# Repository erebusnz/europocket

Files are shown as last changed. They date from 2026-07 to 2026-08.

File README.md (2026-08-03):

# europocket

A Eurorack module that interfaces a **Teenage Engineering Pocket Operator** with a
**Eurorack** modular system. The two domains differ in both clock rate and signal
levels, so the board provides two converters in one:

- **Clock converter** — takes a Eurorack clock/trigger on the input jack and produces
  a Pocket Operator compatible sync signal (÷2, 4 PPQN → 2 PPQN, 0–3.3 V).
- **Level converter** — takes the Pocket Operator's **left and right audio** and
  boosts it from line level to modular level on the two output jacks.

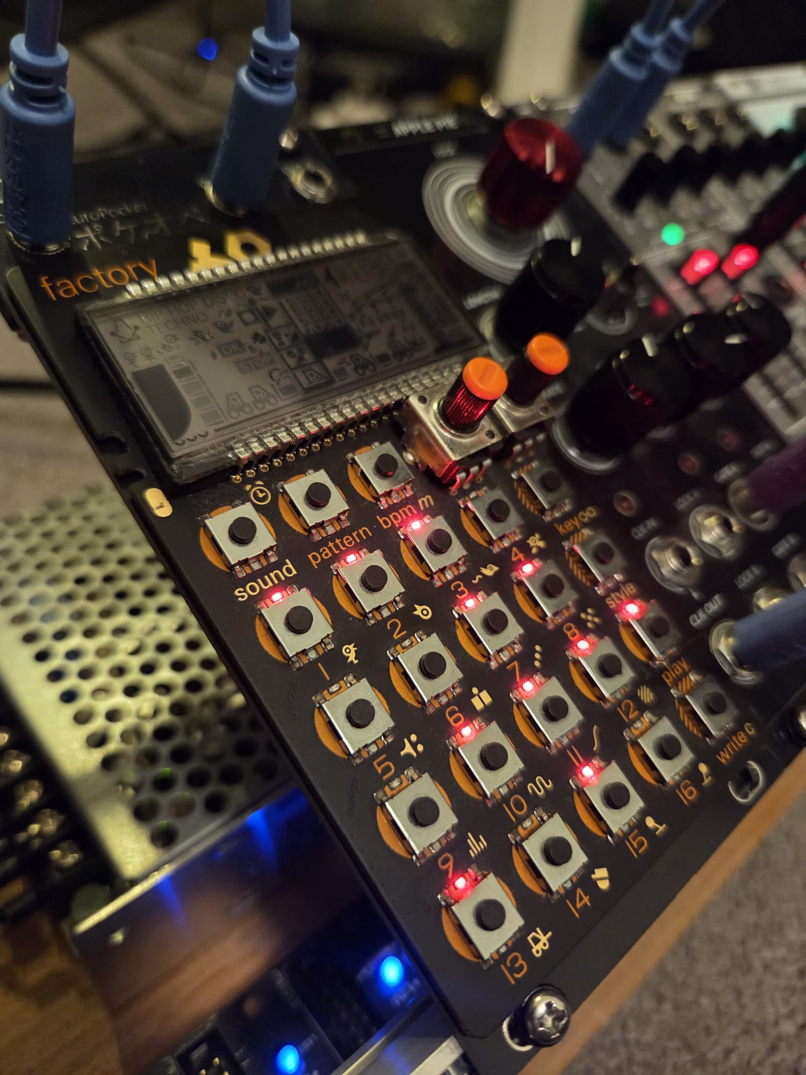
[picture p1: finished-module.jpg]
The finished module installed in a Eurorack case, patched to a PO-32


*The finished module in the rack, clocking and taking audio from a PO-32.*

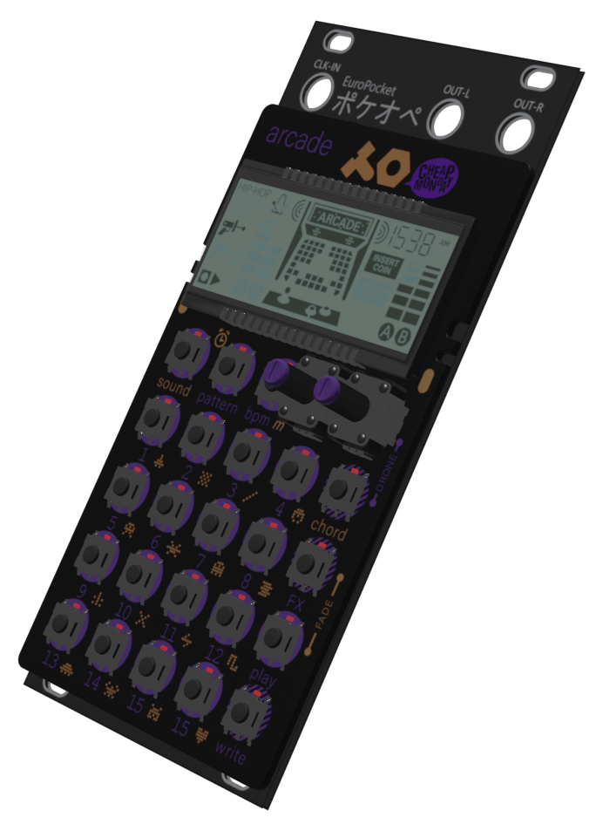
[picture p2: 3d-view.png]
3D view


## Jacks

| Jack | Direction | Signal |
|---|---|---|
| Clock in | Eurorack → board | Eurorack clock/trigger (up to ~10–12 V tolerated) |
| Audio out L | board → Eurorack | Pocket Operator left channel, boosted to ~10 Vpp modular level |
| Audio out R | board → Eurorack | Pocket Operator right channel, boosted to ~10 Vpp modular level |

The Pocket Operator connects via its sync/audio jacks: the converted sync clock goes
to the PO, and the PO's audio comes back into the board's two buffer channels.

## Assembly

> ⚠️ **Use a hot-air rework station.** Attaching europocket requires desoldering the
> jacks from the back of the Pocket Operator. Hot air lifts them cleanly; an iron risks
> pulling the pads off the PO, which is not recoverable.

1. **Desolder the PO's jacks** from the back of the Pocket Operator.
2. **Bond the boards.** Position the europocket PCB on top of the Pocket Operator and
   join the two with **three small sections of 3M 4910F VHB Clear tape**.
3. **Connect the module to the PO.** Solder `PO-R`, `PO-L` and `PO-CLK` to the pads that
   appear in the same box on the Pocket Operator.
4. **Refit the jacks** to the module's own pads — `GND, R, GND, L` for audio and
   `GND, CLK` for the clock.
5. **Wire up Reset.** Solder `Reset` to the **bottom left pin of the Play button** on the
   front of the Pocket Operator, so the divider clears in step with the PO's transport.
6. **Power the PO from the module:**
   - `B−` → **top right** battery terminal
   - `B+` → **bottom left** battery terminal

The module supplies the Pocket Operator from its own +3.3 V regulator in place of the
AAA cells, so the PO runs whenever the rack is powered.

## Pocket Operator setup

Two settings on the PO must be correct or the module will appear dead. Both are
button chords on the master unit.

### Sync mode — set to SY2

> Hold **`key`** and press **`bpm`**. Press repeatedly to cycle through the modes.

**SY2** means *sync in, stereo audio out* — the mode this module expects. It takes the
board's converted clock on its sync input and returns both audio channels.

Pocket Operators share their 3.5 mm jacks between audio and sync, so the other SY modes
repurpose one or both output channels to carry the sync click instead of music. In those
modes the level converter's inputs see **silence**, and the module produces no output
even though every part of it is working correctly.

### Volume — set to full

> Hold **`bpm`** and press **key 16**.

The level converter's gain of ×4.41 is fixed, and it assumes the PO is running at full
output. The ~9.7 Vpp modular-level figure comes from the PO's measured **2.2 Vpp at
loudest volume** — at anything less, the module's output scales down proportionally and
won't reach Eurorack level.

## How it works

**Clock path:** Eurorack trigger → transistor input stage (level shift + protection,
Q1) → RC glitch filter → Schmitt trigger (74AHC1G14) → D flip-flop wired as a toggle
(74HC74, ÷2) → 1 kΩ series output → PO sync. The **Reset** input connects to the
module's Play button and asynchronously clears the divider for deterministic restarts.
Most Eurorack clocks run 4 PPQN; Pocket Operators expect 2 PPQN, hence the
divide-by-two.

**Audio path:** each channel is an inverting TL072 stage running from ±12 V,
gain ≈ ×4.41 (220 kΩ / 49.9 kΩ), taking the PO's measured ~2.2 Vpp output to
~9.7 Vpp. An 18 pF feedback cap rolls off above ~40 kHz — high enough to keep the
PO's square-wave edges crisp.

**Power:** ±12 V from the Eurorack bus (2×05 IDC header, Schottky reverse-polarity
protection). An LM1117 regulates +3.3 V locally for the logic; the TL072 runs
directly from ±12 V.

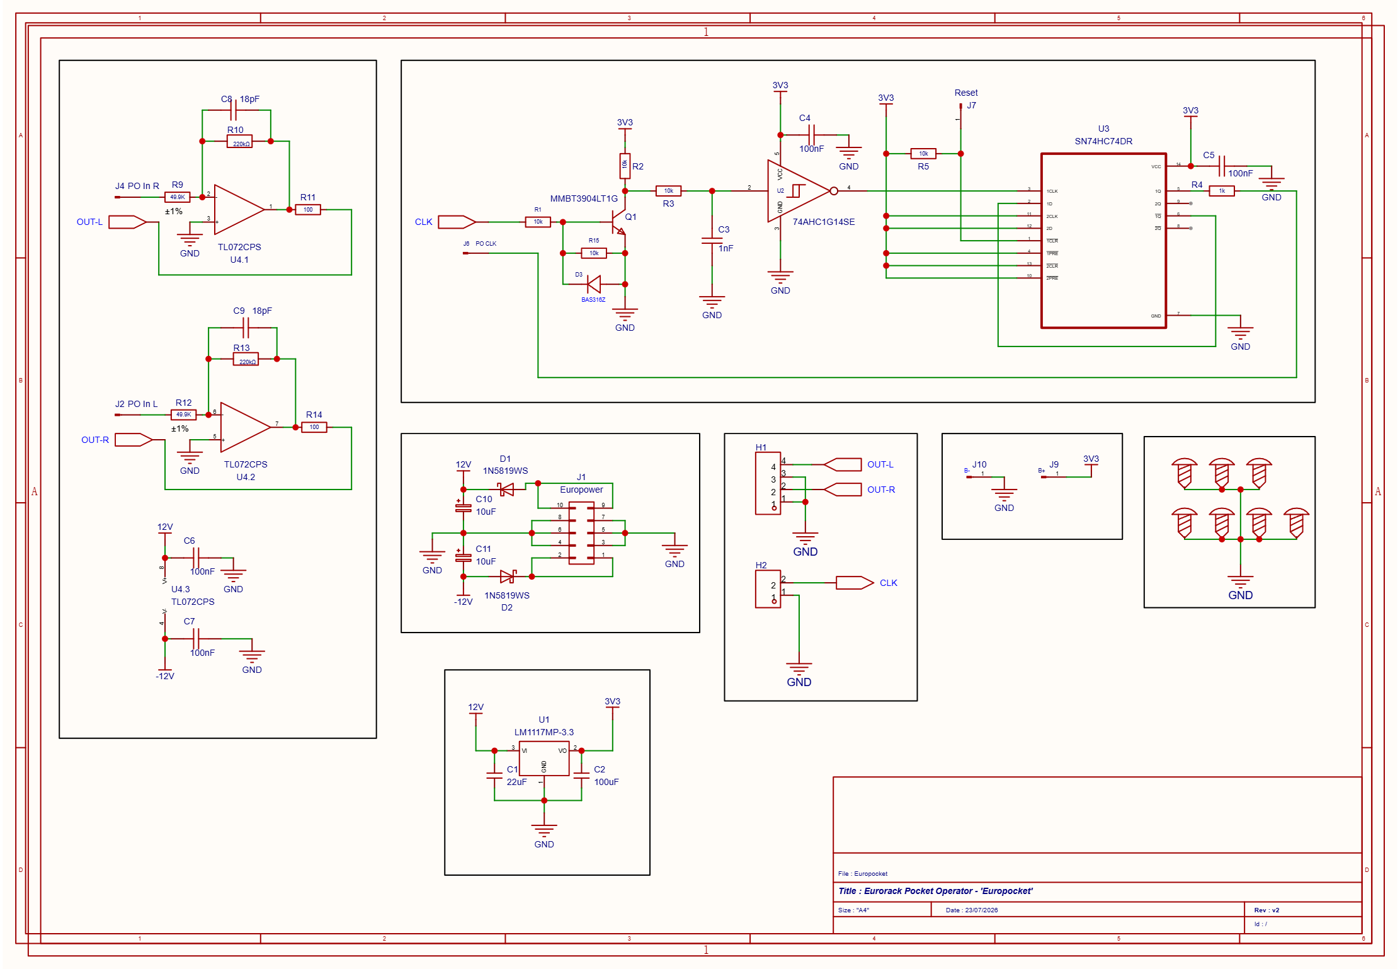
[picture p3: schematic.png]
Schematic


## Bill of materials

**Semiconductors**

| Qty | Reference | Part | Package | Purpose |
|-----|---|---|---|---|
| 1 | U1 | LM1117MP-3.3 | SOT-223 | +12 V → +3.3 V LDO |
| 1 | U2 | 74AHC1G14SE-7 | SOT-353 (SC-70-5) | Schmitt inverter |
| 1 | U3 | SN74HC74DR | SOIC-14 | Dual D flip-flop (÷2) |
| 1 | U4 | TL072CPS | SOIC-8W | Dual op-amp (level converter) |
| 1 | Q1 | MMBT3904LT1G (onsemi) | SOT-23 | NPN input transistor |
| 2 | D1, D2 | 1N5819WS | SOD-123F | Schottky, reverse-polarity protection |
| 1 | D3 | BAS316Z | SOD-323 | Q1 base clamp, negative inputs |

**Resistors** — all 0805

| Qty | Reference | Value | Purpose |
|-----|---|---|---|
| 5 | R1, R2, R3, R5, R15 | 10 kΩ | Base series, collector pull-up, RC filter, /CLR1 pull-up, base pulldown |
| 1 | R4 | 1 kΩ | Sync output series resistor |
| 2 | R9, R12 | 49.9 kΩ | Buffer input resistors |
| 2 | R10, R13 | 220 kΩ | Buffer feedback resistors (×4.41) |
| 2 | R11, R14 | 100 Ω | Buffer output series resistors |

**Capacitors**

| Qty | Reference | Value | Package | Purpose |
|-----|---|---|---|---|
| 4 | C4, C5, C6, C7 | 100 nF | 0805 | Rail decoupling (+3.3 V ×2, +12 V, −12 V) |
| 2 | C8, C9 | 18 pF | 0805 | Buffer feedback caps (~40 kHz pole) |
| 1 | C3 | 1 nF | 0805 | RC filter |
| 1 | C1 | 22 µF | CP_Elec_5×5.3 | +12 V bulk |
| 2 | C10, C11 | 10 µF | CP_Elec_5×5.3 | ±12 V decoupling |
| 1 | C2 | 100 µF | CP_Elec_6.3×5.9 | +3.3 V bulk |

**Connectors and test points**

| Qty | Reference | Part | Purpose |
|-----|---|---|---|
| 1 | J1 | IDC header 2×05 | Eurorack ±12 V / GND bus ("Europower") |
| 1 | H1 | 4-pad row | Audio out L/R + GND |
| 1 | H2 | 2-pin header 2.54 mm | Clock in + GND |
| 6 | J2, J4, J6, J7, J9, J10 | Test pad 4.0×2.0 mm | PO In L/R, PO CLK, Reset, B+, GND |

**Assembly consumables**

| Qty | Item | Purpose |
|-----|---|---|
| 3 | 3M 4910F VHB Clear tape, small sections | Bonding the PCB to the Pocket Operator |

## Repository contents

| File | Description |
|---|---|
| [finished-module.jpg](finished-module.jpg) | Photo of the assembled module in a rack |
| [schematic.pdf](schematic.pdf) / [schematic.png](schematic.png) | Schematic |
| [pcb-top.png](pcb-top.png) / [pcb-bottom.png](pcb-bottom.png) | PCB renders |
| `europocket.eprj2` | EasyEDA Pro project file |
| `gerber/` | Fabrication outputs |
| `datasheets/` | Component datasheets |

## PCB

| Front | Back |
|---|---|
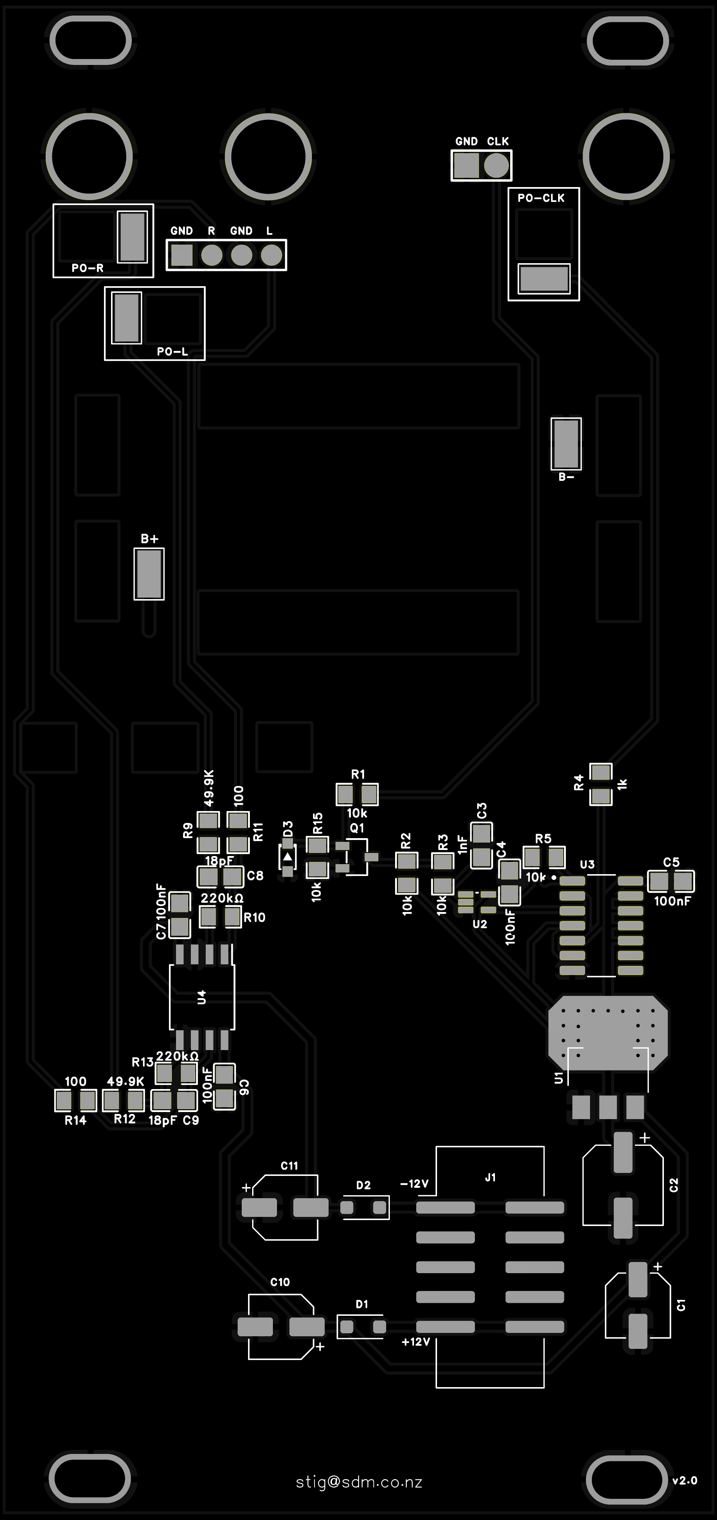
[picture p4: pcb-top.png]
PCB top
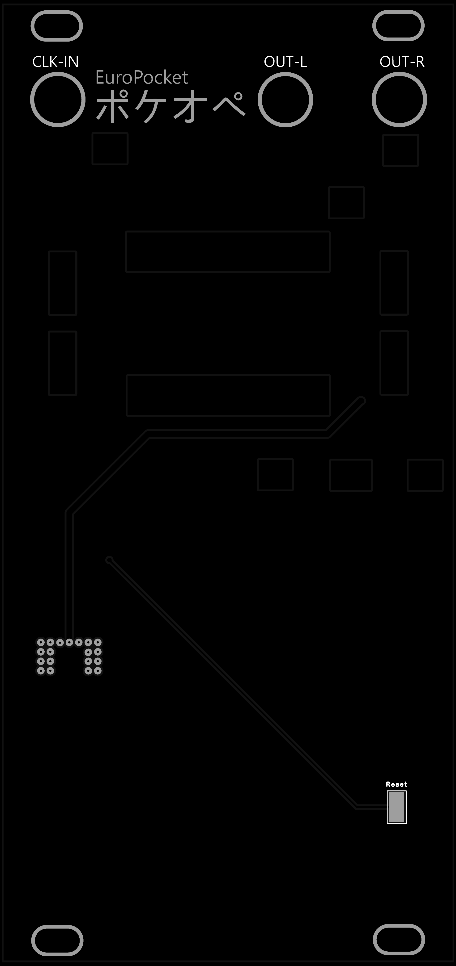
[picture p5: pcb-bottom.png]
PCB bottom
|  |  |

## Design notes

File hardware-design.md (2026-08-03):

# europocket — Hardware Design

Interface between the **Eurorack** and **Pocket Operator (PO)** domains. The two signal
domains differ in both timing (clock rate) and electrical levels, so the design breaks
into three functional blocks: **Power**, **Clock converter**, and **Level converter**.

> Reference designators, values and nets in this document are reconciled against
> `Netlist_europocket_2026-08-03.tel`.
>
> **Designators changed in this revision.** The Europower header moved `J3` → **`J1`**,
> reset moved `J5` → **`J7`**, the buffer and trigger test points were replaced by
> labelled PO test points (`J2`, `J4`, `J6`), and the audio outputs and clock input are
> now headers **`H1`** and **`H2`**. Older notes and captures using the previous
> numbering will not match.

---

## Power

Powered from the **Eurorack bus** via header **J1** ("Europower", 2×05 IDC). The board
takes **±12 V** from the bus and locally regulates **+3.3 V** for the CMOS logic. The
TL072 in the Level converter runs directly from **±12 V**.

**Rails**

| Rail | Source | Consumers |
|---|---|---|
| +12 V | J1 pins 9–10, via D1 | LM1117 input (U1.3), TL072 V+ (U4.8) |
| −12 V | J1 pins 1–2, via D2 | TL072 V− (U4.4) |
| +3.3 V  | LM1117 (U1) output | U2, U3, R2/R5 pull-ups, J9 test point |
| GND | J1 pins 3–8 | all blocks, plus all seven mounting holes |

> **−12 V has exactly one consumer: the op-amp.** Nothing else on the board depends on
> it, so a dead −12 V rail leaves the clock converter working normally while the audio
> path is silent. Check it directly at U4.4 when diagnosing a dead audio path.

**Components**

- `U1` — LM1117MP-3.3 (SOT-223) LDO: **+12 V → +3.3 V** (Vin = U1.3, Vout = U1.2, GND = U1.1).
- `D1`, `D2` — 1N5819WS Schottky, reverse-polarity / mis-insertion protection on the +12 V and −12 V rails.
- Bulk: `C1` 22 µF (+12 V), `C2` 100 µF (+3.3 V), `C10` 10 µF (+12 V), `C11` 10 µF (−12 V).
- Decoupling (100 nF, one per rail/IC, adjacent to the pin): `C4`/`C5` on +3.3 V (U2/U3), `C6` on +12 V, `C7` on −12 V.

Measured on hardware (2026-08-03): **+11.2 V** at U4.8 and **−12.1 V** at U4.4 — the
asymmetry is bus tolerance plus the Schottky drop, and it means the positive half of the
audio waveform clips roughly a volt before the negative half.

---

## Clock converter

### Eurorack Trigger → Pocket Operator Sync Converter

**Purpose.** Convert a Eurorack clock/trigger into a Pocket Operator compatible sync
signal. The design assumes a **4 PPQN** Eurorack clock and produces a **2 PPQN** Pocket
Operator sync clock by dividing the clock by two.

**Requirements**

- Accept Eurorack triggers up to approximately **10–12 V**.
- Protect the logic from overvoltage and from negative excursions.
- Reject narrow glitches.
- Produce clean **3.3 V CMOS** logic.
- Divide clock by two.
- Provide deterministic reset.

#### Functional block diagram

```
Eurorack Trigger (H2.2)
        │
        ▼
Input Protection / Level Shift   (Q1, R1, R15, D3)
        │
        ▼
RC Noise Filter                  (R3 / C3)
        │
        ▼
Schmitt Trigger Inverter         (U2, 74AHC1G14)
        │
        ▼
Toggle Flip-Flop (÷2)            (U3, 74HC74)
        │
        ▼
Pocket Operator Sync Output      (R4 → J6)
```

#### Stage 1 — Input conditioning

**Connector H2 (clock in):** H2.2 = Eurorack clock, H2.1 = GND.

**Components**

- `Q1` — MMBT3904 (SOT-23) NPN
- `R1` — 10 kΩ (base series)
- `R2` — 10 kΩ collector pull-up to 3.3 V
- `R15` — 10 kΩ base–emitter pulldown
- `D3` — SOD-323 small-signal diode, base clamp

**Wiring**

```
Clock input (H2.2) → R1 → Q1 base ─┬─ R15 → GND
                                    └─ D3 cathode (anode → GND)
Q1 emitter    → GND
Q1 collector  → R2 pull-up to 3.3 V   (collector = logic signal)
```

**Behaviour**

| Input | Collector |
|---|---|
| Low | High |
| High  | Low |

The transistor **level shifts**, **protects** the logic, and **inverts**.

**Why R15 and D3 are present.** Without the `R15` pulldown the stage switches at a single
V_BE (~0.65 V). A Eurorack clock source measured on hardware idles **low at ~0.68 V**,
above that threshold — so Q1 never turns off and the collector sticks low. R15 divides the
base voltage and lifts the effective threshold to ~1.3 V:

| Input | Base voltage (with R15) | Q1 |
|---|---|----|
| Low 0.68 V  | ÷2 → 0.34 V | off ✓ |
| High 4.7 V  | Thevenin 2.34 V / 5 kΩ → I_B ≈ 0.33 mA | saturated ✓ |

`D3` clamps negative inputs at −0.6 V. Bipolar Eurorack signals (±5 V/±8 V LFOs, or audio
used as a clock) would otherwise reverse-bias Q1's base–emitter junction; V_EBO(max) is
only 6 V, and repeated B–E avalanche permanently degrades hFE. R1 limits the clamp
current for inputs down to at least −12 V.

#### Stage 2 — Noise filter

**Components:** `R3` = 10 kΩ, `C3` = 1 nF → **time constant ≈ 10 µs**.

```
Q1 collector
     │
     R3
     │
     +------> Schmitt Trigger input (U2.2)
     │
     C3
     │
    GND
```

**Purpose:** remove spikes, slightly slow edges before the Schmitt trigger.

#### Stage 3 — Schmitt trigger

**Device:** `U2` — 74AHC1G14SE-7 (single inverting Schmitt trigger, **SOT-353/SC-70-5** —
the `SE` suffix; 0.65 mm pitch, smaller than SOT-23-5).

- Power: VCC = 3.3 V (U2.5), GND (U2.3), 100 nF decoupling.
- Input: U2.2, from the RC network.
- Output: U2.4, clean digital clock — restores fast logic edges.

#### Stage 4 — Clock divider

**Device:** `U3` — SN74HC74DR (dual D flip-flop, SOIC-14). **First flip-flop only.**

- Power: VCC = 3.3 V (U3.14), GND (U3.7), 100 nF decoupling.
- Clock: `1CLK` (U3.3) ← Schmitt output (U2.4).
- Toggle configuration: `1D` (U3.2) ← `1Q̄` (U3.6) — converts the D flip-flop into a T flip-flop.

**Result:** every rising edge, `1Q` toggles → **output frequency = input frequency / 2**.

**Reset**

External reset via test point **J7 ("Reset")**, asynchronously clearing the first
flip-flop. On the assembled module this connects to the PO's Play button, so the divider
restarts deterministically.

- `/CLR1` (U3.1) — J7 with 10 kΩ pull-up `R5` to 3.3 V; drive low to reset.
- `/PRE1` (U3.4) — tied directly to 3.3 V (inactive).

**Unused second flip-flop.** All four inputs are tied to 3.3 V — `/PRE2` (U3.10),
`2CLK` (U3.11), `2D` (U3.12), `/2CLR` (U3.13). Outputs `2Q` (U3.9) and `2Q̄` (U3.8) are
left open. A static high on 2CLK is as valid as a static low: what matters is that no
input floats, since a floating HC clock input can self-oscillate and raise supply
current. The previous revision's discrete pull-ups R6/R7/R8 are no longer fitted.

#### Output

`1Q` (U3.5) → **1 kΩ series resistor `R4`** → test point **J6 ("PO CLK")**.

- Purpose of resistor: short-circuit protection, cable protection, output current limiting.
- Output amplitude: **0–3.3 V**.

Verified on hardware: 5.556 Hz in → 2.747 Hz out (÷2), 0–3.3 V, ~50 % duty.

#### Expected timing

```
Input (4 PPQN)   | | | | | | | |
Schmitt Output   | | | | | | | |
Flip-Flop Output __----____----____
```

Transitions occur every second input pulse — equivalent to **2 PPQN**.

---

## Level converter

Two independent buffer/amplifier channels built on a dual **TL072 (U4)** running from
**±12 V**. Each channel is an inverting stage with the non-inverting input grounded.

**Per-channel topology**

```
In (J2 / J4) → R_in ──┬── (−) op-amp ── out ── R_series ── Out (H1)
                      │                    │
                      └──── R_fb ──────────┤
                      └──── C_fb ──────────┘
             (+) op-amp → GND
```

| Element | Channel A | Channel B | Value |
|---|---|---|---|
| Op-amp | U4 A (in − U4.2, out U4.1) | U4 B (in − U4.6, out U4.7) | — |
| Input | J4 "PO In R" | J2 "PO In L" | — |
| Input resistor | R9 | R12 | 49.9 kΩ  |
| Feedback | R10 | R13 | 220 kΩ |
| Feedback cap | C8 | C9 | 18 pF |
| Output series  | R11 | R14 | 100 Ω |
| Output | H1.4 "OUT-L" | H1.2 "OUT-R" | — |

- **Direction:** Pocket Operator output → Eurorack (boost line level up to modular level).
- **Gain:** −R_fb / R_in = −220 kΩ / 49.9 kΩ ≈ **−4.41**.
- **Level:** the PO's measured **2.2 Vpp** output (loudest volume, steady note, near-square
  chip voice) becomes **~9.7 Vpp** — standard Eurorack modular level, comfortably inside
  the TL072's ~21 Vpp swing on ±12 V.
- **Roll-off:** the feedback cap sets a pole at `1/(2π·R_fb·C_fb)` = 1/(2π·220 k·18 pF) ≈
  **40.2 kHz**. The PO voice is a near-square wave whose harmonics extend well above the
  fundamental, so the pole is deliberately kept above ~30 kHz — lower would round the
  edges and dull the tone.
- Powered from the ±12 V rails, so output can swing well beyond the 3.3 V logic domain.

**The gain assumes full PO volume.** 2.2 Vpp is the measurement at loudest; at lower
volume settings the output scales down proportionally and will not reach modular level.

**U4 orientation.** The silkscreen has no pin-1 marker. Use the decoupling caps: **C7
(−12 V) is adjacent to pin 4**, **C6 (+12 V) is adjacent to pin 8**. With the board
oriented as in `pcb-top.png`, the top row is pins 4-3-2-1 left to right and the bottom
row is 5-6-7-8, putting **pin 1 at the top-right**. Pins 4 and 8 are diagonally opposite,
so a 180° rotation swaps VCC+ and VCC− exactly — the worst mis-orientation this package
allows. Probe the C6/C7 pads rather than the gull-wing leads: same nets, far larger
targets, and a disagreement between pad and lead reveals an open joint.

---

## Connectors and test points

| Ref | Label | Function |
|-----|---|---|
| J1  | Europower  | Eurorack ±12 V / GND bus header (IDC 2×05) |
| H1  | — | Audio out: H1.4 = OUT-L, H1.2 = OUT-R, H1.1/H1.3 = GND |
| H2  | — | Clock in: H2.2 = signal, H2.1 = GND |
| J2  | PO In L | Pocket Operator left audio in |
| J4  | PO In R | Pocket Operator right audio in |
| J6  | PO CLK | Converted 2 PPQN sync out to the PO |
| J7  | Reset | Divider reset (drives /CLR1 low) |
| J9  | B+ | +3.3 V out to the PO's battery + terminal |
| J10 | GND | Ground test point |
| SCREW1–4 | — | M3 mounting holes, tied to GND |
| SCREW5–7 | — | 3.5 mm socket holes, tied to GND |

---

## Bill of materials

See [README.md](README.md#bill-of-materials) — kept there as the single source of truth
so the two documents cannot drift apart.

---

## Design notes

- The divider assumes the Eurorack source is 4 PPQN, matching the common default for many
  sequencers and clock generators. Pocket Operators expect 2 PPQN sync, making a
  divide-by-two stage appropriate.
- The transistor input stage tolerates a wide range of Eurorack trigger voltages without
  exposing the logic ICs to more than 3.3 V.
- The Schmitt trigger ensures reliable operation with slow edges or noisy clocks.
- The 74HC74 is configured as a T flip-flop (D = /Q), yielding a stable 50% duty-cycle
  output.
- Reference-designator note: on this board **U1 = regulator, U2 = Schmitt, U3 = flip-flop,
  U4 = op-amp** — earlier drafts of the clock-converter section numbered the Schmitt/flip-flop
  as U1/U2.
- If broader compatibility is desired, consider adding a jumper or switch to bypass the
  divider for Eurorack sources already configured to 2 PPQN. This allows selecting either
  a direct 1:1 clock or the default ÷2 output.

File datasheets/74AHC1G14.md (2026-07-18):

# 74AHC1G14 -- Single Schmitt-Trigger Inverter Gate

## BOM Details

| Field | Value |
|---|---|
| MPN | 74AHC1G14SE-7 |
| Manufacturer | Diodes Incorporated |
| Package/Footprint | SOT-353 (SC-88A / SOT65P210X110-5N) |
| Designator | U2 |
| Quantity | 1 |
| Supplier Part | -- |

## Description

The 74AHC1G14 is a single 1-input Schmitt-trigger inverter gate with a standard push-pull output, performing the Boolean function Y = NOT A. It operates over a 2.0 V to 5.5 V supply range and delivers +/-8 mA output drive at 5.0 V. The Schmitt-trigger input provides hysteresis that makes the device tolerant of slow input rise and fall times, allowing it to clean up noisy or slowly-changing signals into fast, clean logic transitions. The SE suffix denotes the 5-pin SOT-353 package.

## Key Electrical Characteristics

| Parameter | Min | Typ | Max | Unit | Condition |
|---|---|---|---|---|---|
| Supply Voltage (VCC) | 2.0 | -- | 5.5 | V | Operating range |
| Positive-going Threshold (VT+) | -- | 3.15 | -- | V | VCC = 4.5 V, 25 deg C |
| Negative-going Threshold (VT-) | -- | 1.35 | -- | V | VCC = 4.5 V, 25 deg C |
| Hysteresis (VT+ - VT-) | 0.4 | -- | 1.4 | V | VCC = 4.5 V |
| High-Level Output Voltage (VOH) | 3.94 | -- | -- | V | VCC = 4.5 V, IOH = -8 mA |
| Low-Level Output Voltage (VOL) | -- | -- | 0.36 | V | VCC = 4.5 V, IOL = 8 mA |
| Output Drive (IOH / IOL) | -- | -- | +/-8 | mA | VCC = 5 V +/-0.5 V |
| Input Current (II) | -- | -- | +/-0.1 | uA | VI = 5.5 V or GND, 25 deg C |
| Supply Current (ICC) | -- | 1 | 10 | uA | VI = 5.5 V or GND, IO = 0 |
| Input Capacitance (CI) | -- | 2.0 | 10 | pF | VCC = 5.5 V |
| Propagation Delay (tpd) | -- | 3.2 | 8.6 | ns | VCC = 5 V, CL = 15 pF, 25 deg C |

## Pinout

SOT-353 (5-pin), top view.

| Pin # | Name | Direction | Description |
|---|---|---|---|
| 1 | NC | -- | No connection |
| 2 | A | I | Data input |
| 3 | GND | P | Ground |
| 4 | Y | O | Data output (inverted) |
| 5 | VCC | P | Supply voltage |

**Function Table**

| A | Y |
|---|---|
| H | L |
| L | H |

## Absolute Maximum Ratings

| Parameter | Value | Unit |
|---|---|---|
| Supply Voltage Range (VCC) | -0.5 to 6.5 | V |
| Input Voltage Range (VI) | -0.5 to 6.5 | V |
| Output Voltage (VO) | -0.5 to VCC + 0.5 | V |
| Input Clamp Current (IIK), VI < 0 | -20 | mA |
| Output Clamp Current (IOK) | +/-20 | mA |
| Continuous Output Current (IO) | +/-25 | mA |
| Continuous Current through VCC | 50 | mA |
| Continuous Current through GND | -50 | mA |
| Operating Junction Temperature (TJ) | -40 to 150 | deg C |
| Storage Temperature | -65 to 150 | deg C |
| ESD (HBM) | 2 | kV |
| ESD (CDM) | 1 | kV |

## Application Notes

- **Schmitt-trigger signal conditioning:** The input hysteresis (typically ~1.8 V at VCC = 4.5 V between VT+ and VT-) makes this gate ideal for squaring up slow, noisy, or RC-shaped edges -- for example debouncing a mechanical switch, cleaning up a slow power-on ramp, or conditioning a signal before feeding a standard (non-Schmitt) CMOS clock input. In this project U2 conditions a trigger/clock edge before the SN74HC74 flip-flop (U3) clock input.
- **Unused inputs:** Do not leave the input floating. Any unused Schmitt-trigger input should be tied firmly to VCC or GND to prevent oscillation and excess supply current. (There is only one input here; ensure it is always driven.)
- **Power supply decoupling:** Place a 100 nF ceramic bypass capacitor directly across pins 5 (VCC) and 3 (GND) with short traces. Even a single-gate logic device can inject switching noise onto the rail, and the fast output edges benefit from a low-impedance local supply.
- **Output edge rates and loading:** The push-pull output produces fast edges (tpd ~3 ns at 5 V). Into long traces or reactive loads this can ring; add a small series resistor (e.g. 33-100 ohm) at the output if reflections or overshoot are observed on the driven node.
- **Voltage tolerance:** Inputs and outputs must stay within -0.5 V to VCC + 0.5 V. The device is not 5 V tolerant above VCC; do not drive the input above the supply rail.

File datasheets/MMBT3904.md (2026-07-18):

# MMBT3904 -- NPN General-Purpose Switching Transistor (SOT-23)

## BOM Details

| Field | Value |
|---|---|
| MPN | MMBT3904LT1G |
| Manufacturer | onsemi |
| Package/Footprint | SOT-23 (TO-236), CASE 318, Style 6 |
| Designator | Q1 |
| Quantity | 1 |
| Supplier Part | -- |

## Description

The MMBT3904 is a silicon NPN general-purpose bipolar transistor, the surface-mount (SOT-23) equivalent of the classic 2N3904. It is designed for general-purpose switching and amplifier applications, offering a 40 V collector-emitter breakdown, 200 mA continuous collector current, and a 300 MHz gain-bandwidth product. It is well suited for low-power switching (driving relays, LEDs, or logic-level loads) and small-signal amplification. The device is Pb-free, halogen-free, and RoHS compliant.

## Key Electrical Characteristics

| Parameter | Min | Typ | Max | Unit | Condition |
|---|---|---|---|---|---|
| DC Current Gain (hFE) | 100 | -- | 300 | -- | IC = 10 mAdc, VCE = 1.0 V |
| DC Current Gain (hFE) | 30 | -- | -- | -- | IC = 100 mAdc, VCE = 1.0 V |
| Collector-Emitter Saturation (VCE(sat)) | -- | -- | 0.2 | V | IC = 10 mAdc, IB = 1.0 mAdc |
| Collector-Emitter Saturation (VCE(sat)) | -- | -- | 0.3 | V | IC = 50 mAdc, IB = 5.0 mAdc |
| Base-Emitter Saturation (VBE(sat)) | 0.65 | -- | 0.85 | V | IC = 10 mAdc, IB = 1.0 mAdc |
| Collector Cutoff Current (ICEX) | -- | -- | 50 | nAdc | VCE = 30 V, VEB = 3.0 V |
| Gain-Bandwidth Product (fT) | 300 | -- | -- | MHz | IC = 10 mA, VCE = 20 V, f = 100 MHz |
| Output Capacitance (Cobo) | -- | -- | 4.0 | pF | VCB = 5.0 V, f = 1.0 MHz |
| Input Capacitance (Cibo) | -- | -- | 8.0 | pF | VEB = 0.5 V, f = 1.0 MHz |
| Turn-On Delay + Rise (td, tr) | -- | -- | 35 | ns | IC = 10 mA, IB1 = 1.0 mA |
| Storage Time (ts) | -- | -- | 200 | ns | IC = 10 mA, IB1 = IB2 = 1.0 mA |
| Fall Time (tf) | -- | -- | 50 | ns | IC = 10 mA, IB1 = IB2 = 1.0 mA |

## Pinout

SOT-23 (TO-236), CASE 318, Style 6.

| Pin # | Name | Description |
|---|---|---|
| 1 | Base | Base terminal |
| 2 | Emitter | Emitter terminal |
| 3 | Collector | Collector terminal |

## Absolute Maximum Ratings

| Parameter | Symbol | Value | Unit |
|---|---|---|---|
| Collector-Emitter Voltage | VCEO | 40 | Vdc |
| Collector-Base Voltage | VCBO | 60 | Vdc |
| Emitter-Base Voltage | VEBO | 6.0 | Vdc |
| Collector Current -- Continuous | IC | 200 | mAdc |
| Collector Current -- Peak | ICM | 900 | mAdc |
| Total Device Dissipation (FR-5, 25 deg C) | PD | 225 | mW |
| Thermal Resistance (Junction-to-Ambient) | RthJA | 556 | deg C/W |
| Junction / Storage Temperature | TJ, Tstg | -55 to +150 | deg C |

## Application Notes

- **Saturated switch operation:** For a hard-on saturated switch, drive the base with enough current to keep IC/IB around 10 (e.g. IB = 1 mA for IC = 10 mA). At that drive VCE(sat) is only ~0.2 V. Always include a base current-limiting resistor sized from (V_drive - VBE) / IB; VBE(on) is roughly 0.7 V when conducting.
- **Base resistor and pull-down:** When driven from a logic output or an RC network, a series base resistor sets the drive current and a resistor from base to emitter (typ 10 k) ensures the transistor stays firmly off when the driver is high-impedance and speeds turn-off by removing stored charge.
- **Inductive loads:** When switching a relay or other inductive load, place a flyback (freewheeling) diode across the load to clamp the collector voltage spike below the 40 V VCEO limit at turn-off.
- **Power dissipation:** In the SOT-23 package total dissipation is limited to ~225 mW at 25 deg C (derate 1.8 mW/deg C above 25 deg C). Keep the collector current and VCE product within the safe operating area, and provide adequate copper for heat spreading if operating near the current limit.
- **2N3904 equivalence:** The MMBT3904 is functionally identical to the through-hole 2N3904; the same design values apply, but note the SOT-23 pinout (1=Base, 2=Emitter, 3=Collector) differs from the TO-92 pinout and from many other SOT-23 transistors.

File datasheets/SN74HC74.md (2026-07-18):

# SN74HC74 -- Dual D-Type Positive-Edge-Triggered Flip-Flop with Preset and Clear

## BOM Details

| Field | Value |
|---|---|
| MPN | SN74HC74DR |
| Manufacturer | Texas Instruments |
| Package/Footprint | SOIC-14 (D package, SOIC127P600X175-14N) |
| Designator | U3 |
| Quantity | 1 |
| Supplier Part | -- |

## Description

The SN74HC74 contains two independent D-type positive-edge-triggered flip-flops, each with asynchronous active-low preset and clear inputs. On the rising edge of the clock, the value on the D input is transferred to the Q output. The high-speed CMOS device operates over a 2 V to 6 V supply range and can drive up to 10 LSTTL loads. Common uses include dividing a clock by 2 or 4 and converting a momentary push-button into a toggle (latching) function -- the latter being the role of U3 in this project.

## Key Electrical Characteristics

| Parameter | Min | Typ | Max | Unit | Condition |
|---|---|---|---|---|---|
| Supply Voltage (VCC) | 2 | 5 | 6 | V | -- |
| High-Level Output Voltage (VOH) | 3.98 | 4.3 | -- | V | VCC = 4.5 V, IOH = -4 mA |
| Low-Level Output Voltage (VOL) | -- | 0.17 | 0.26 | V | VCC = 4.5 V, IOL = 4 mA |
| Input Leakage Current (II) | -- | -- | +/-0.1 | uA | VI = VCC or 0, VCC = 6 V |
| Supply Current (ICC) | -- | -- | 4 | uA | VI = VCC or 0, IO = 0, VCC = 6 V |
| Input Capacitance (Ci) | -- | 3 | 10 | pF | VCC = 2 V to 6 V |
| Max Clock Frequency (fmax) | 31 | 50 | -- | MHz | VCC = 4.5 V, 25 deg C |
| Propagation Delay (CLK to Q/Q) | -- | 20 | 35 | ns | VCC = 4.5 V, 25 deg C |
| Propagation Delay (PRE/CLR to Q/Q) | -- | 20 | 46 | ns | VCC = 4.5 V, 25 deg C |
| Setup Time (data before CLK rising) | 20 | -- | -- | ns | VCC = 4.5 V, 25 deg C |
| Hold Time (data after CLK rising) | 0 | -- | -- | ns | VCC = 4.5 V |
| Pulse Duration (PRE or CLR low) | 20 | -- | -- | ns | VCC = 4.5 V, 25 deg C |

## Pinout

SOIC-14 (D package), top view. Two flip-flops share VCC (pin 14) and GND (pin 7).

| Pin # | Name | Direction | Description |
|---|---|---|---|
| 1 | 1CLR | I | Flip-flop 1 clear, active low |
| 2 | 1D | I | Flip-flop 1 data input |
| 3 | 1CLK | I | Flip-flop 1 clock, positive-edge triggered |
| 4 | 1PRE | I | Flip-flop 1 preset, active low |
| 5 | 1Q | O | Flip-flop 1 output |
| 6 | 1Q# | O | Flip-flop 1 inverted output |
| 7 | GND | P | Ground |
| 8 | 2Q# | O | Flip-flop 2 inverted output |
| 9 | 2Q | O | Flip-flop 2 output |
| 10 | 2PRE | I | Flip-flop 2 preset, active low |
| 11 | 2CLK | I | Flip-flop 2 clock, positive-edge triggered |
| 12 | 2D | I | Flip-flop 2 data input |
| 13 | 2CLR | I | Flip-flop 2 clear, active low |
| 14 | VCC | P | Positive supply |

**Function Table** (per flip-flop; X = don't care, up-arrow = rising clock edge)

| PRE | CLR | CLK | D | Q | Q# |
|---|---|---|---|---|---|
| L | H | X | X | H | L |
| H | L | X | X | L | H |
| L | L | X | X | H* | H* |
| H | H | up | H | H | L |
| H | H | up | L | L | H |
| H | H | L | X | Q0 | Q0# |

\* Nonstable: does not persist once PRE or CLR returns high.

## Absolute Maximum Ratings

| Parameter | Value | Unit |
|---|---|---|
| Supply Voltage (VCC) | -0.5 to 7 | V |
| Input Clamp Current (IIK), VI < -0.5 V or VI > VCC | +/-20 | mA |
| Output Clamp Current (IOK) | +/-20 | mA |
| Continuous Output Current (IO) | +/-25 | mA |
| Continuous Current through VCC or GND | +/-50 | mA |
| Junction Temperature (TJ) | 150 | deg C |
| Storage Temperature | -65 to 150 | deg C |
| ESD (HBM) | +/-2000 | V |
| ESD (CDM) | +/-1500 | V |

## Application Notes

- **Momentary-to-toggle (T flip-flop) configuration:** Tie the D input to the inverted output (Q#) so each rising clock edge toggles Q. Debounce and condition the momentary switch through a Schmitt-trigger buffer (the 74AHC1G14, U2, in this design) into CLK. This turns a cheap momentary button into a latching on/off toggle.
- **Power-on reset:** Use the asynchronous active-low CLR (or PRE) with an RC network to force a known output state at power-up. A resistor to VCC and capacitor to ground on the CLR pin holds it low briefly at power-on, guaranteeing Q starts LOW before normal clocking begins.
- **Unused inputs must be tied off:** Never leave any input (D, CLK, PRE, CLR) floating -- doing so causes excess supply current and unpredictable behavior. Tie unused PRE/CLR to VCC (inactive) and unused D/CLK to VCC or GND. If a whole second flip-flop is unused, tie all its inputs to defined levels.
- **Clock edge quality:** These are standard (non-Schmitt) CMOS inputs and require fast, clean, monotonic edges at CLK. A slow or bouncy clock edge can cause multiple triggering or metastability -- always drive CLK from a buffer/Schmitt device, not directly from a switch or slow RC.
- **Decoupling:** Place a 100 nF ceramic capacitor between pin 14 (VCC) and pin 7 (GND), as close to the device as possible, to supply the transient current of the output switching.

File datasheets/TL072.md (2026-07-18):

# TL072 -- Dual Low-Noise JFET-Input General-Purpose Operational Amplifier

## BOM Details

| Field | Value |
|---|---|
| MPN | TL072CPS |
| Manufacturer | Texas Instruments |
| Package/Footprint | SOIC-8W_5.3x5.3mm_P1.27mm (PS / SO-8) |
| Designator | U4 |
| Quantity | 1 |
| Supplier Part | -- |

## Description

The TL072 is a dual low-noise JFET-input operational amplifier from Texas Instruments, offering high input impedance, low noise (37 nV/sqrt(Hz) typical at 1 kHz), and low harmonic distortion (0.003% typical). It features a 3 MHz gain-bandwidth product, 13 V/us slew rate, and internal short-circuit protection, making it well suited for audio signal conditioning, active filtering, and buffer applications. In this project U4 provides two output buffer channels ("Buffer 1" and "Buffer 2"). The TL072C is the commercial temperature grade rated for 0 deg C to 70 deg C operation.

## Key Electrical Characteristics

| Parameter | Min | Typ | Max | Unit | Condition |
|---|---|---|---|---|---|
| Gain-Bandwidth Product (GBW) | -- | 3 | -- | MHz | -- |
| Slew Rate (SR) | -- | 13 | -- | V/us | -- |
| Input Offset Voltage (Vos) | -- | -- | 6 | mV | TA = 25 deg C |
| Input Bias Current (Ib) | -- | 65 | 200 | pA | TA = 25 deg C |
| Input Offset Current (Ios) | -- | -- | 100 | pA | TA = 25 deg C |
| Supply Voltage Range (VCC) | +/-2.25 | -- | +/-20 | V | +/-2.25 V to +/-20 V (4.5 V to 40 V) |
| Supply Current (per channel) | -- | 1.4 | 2.8 | mA | VCC = +/-15 V, no load |
| Input Common-Mode Voltage Range | VCC- + 4 | -- | VCC+ | V | -- |
| Output Voltage Swing | +/-12 | -- | +/-13.5 | V | RL >= 2 kohm, VCC = +/-15 V |
| Total Harmonic Distortion | -- | 0.003 | -- | % | -- |
| Equivalent Input Noise Voltage | -- | 37 | -- | nV/sqrt(Hz) | f = 1 kHz |
| CMRR | 80 | 100 | -- | dB | -- |

## Pinout

SOIC-8 (PS package), standard dual op-amp pinout.

| Pin # | Name | Direction | Description |
|---|---|---|---|
| 1 | 1OUT | O | Output, amplifier 1 |
| 2 | 1IN- | I | Inverting input, amplifier 1 |
| 3 | 1IN+ | I | Non-inverting input, amplifier 1 |
| 4 | VCC- | P | Negative supply voltage |
| 5 | 2IN+ | I | Non-inverting input, amplifier 2 |
| 6 | 2IN- | I | Inverting input, amplifier 2 |
| 7 | 2OUT | O | Output, amplifier 2 |
| 8 | VCC+ | P | Positive supply voltage |

## Absolute Maximum Ratings

| Parameter | Value | Unit |
|---|---|---|
| Supply Voltage (VCC+ to VCC-) | 40 | V |
| Differential Input Voltage | +/-30 | V |
| Input Voltage Range | +/-20 | V |
| Output Short-Circuit Duration | Continuous | -- |
| Operating Temperature (TL072C) | 0 to 70 | deg C |
| Storage Temperature | -65 to 150 | deg C |
| Junction Temperature | 150 | deg C |
| Lead Temperature (soldering, 10 s) | 260 | deg C |

## Application Notes

- **JFET input characteristics:** The JFET input stage provides extremely high input impedance (approximately 10^12 ohm) and very low input bias current (65 pA typical), making the TL072 suitable for high-impedance source circuits and buffer stages where bipolar-input op-amps would introduce unacceptable loading or DC errors.
- **Power supply decoupling:** Place 100 nF ceramic bypass capacitors as close as physically possible to pins 4 (VCC-) and 8 (VCC+), with short traces to the ground plane. For audio or supply-noise-sensitive circuits, add bulk electrolytic capacitors (e.g. 10 uF) in parallel with the ceramics on each rail. This project supplies U4 from +/-12 V rails.
- **Dual-supply operation:** In this design the TL072 runs from the +12 V / -12 V rails, giving a wide, symmetric output swing (approximately +/-10 V into a 2 kohm load) well suited to buffering bipolar audio/CV signals.
- **Input common-mode range limits:** The input common-mode voltage range extends from VCC- + 4 V up to VCC+. With +/-12 V supplies, the valid input range is approximately -8 V to +12 V. Driving the input below the lower limit can cause output phase reversal, where the JFET input stage loses control and the output latches toward the opposite rail. Keep inputs within the specified range during all operating conditions including transients.
- **Stability with capacitive loads:** As with most op-amps, a large capacitive load directly on the output can cause peaking or oscillation. If driving a cable or capacitive node, add a small series resistor (typ 22-100 ohm) at the output, optionally inside the feedback loop, to preserve phase margin.

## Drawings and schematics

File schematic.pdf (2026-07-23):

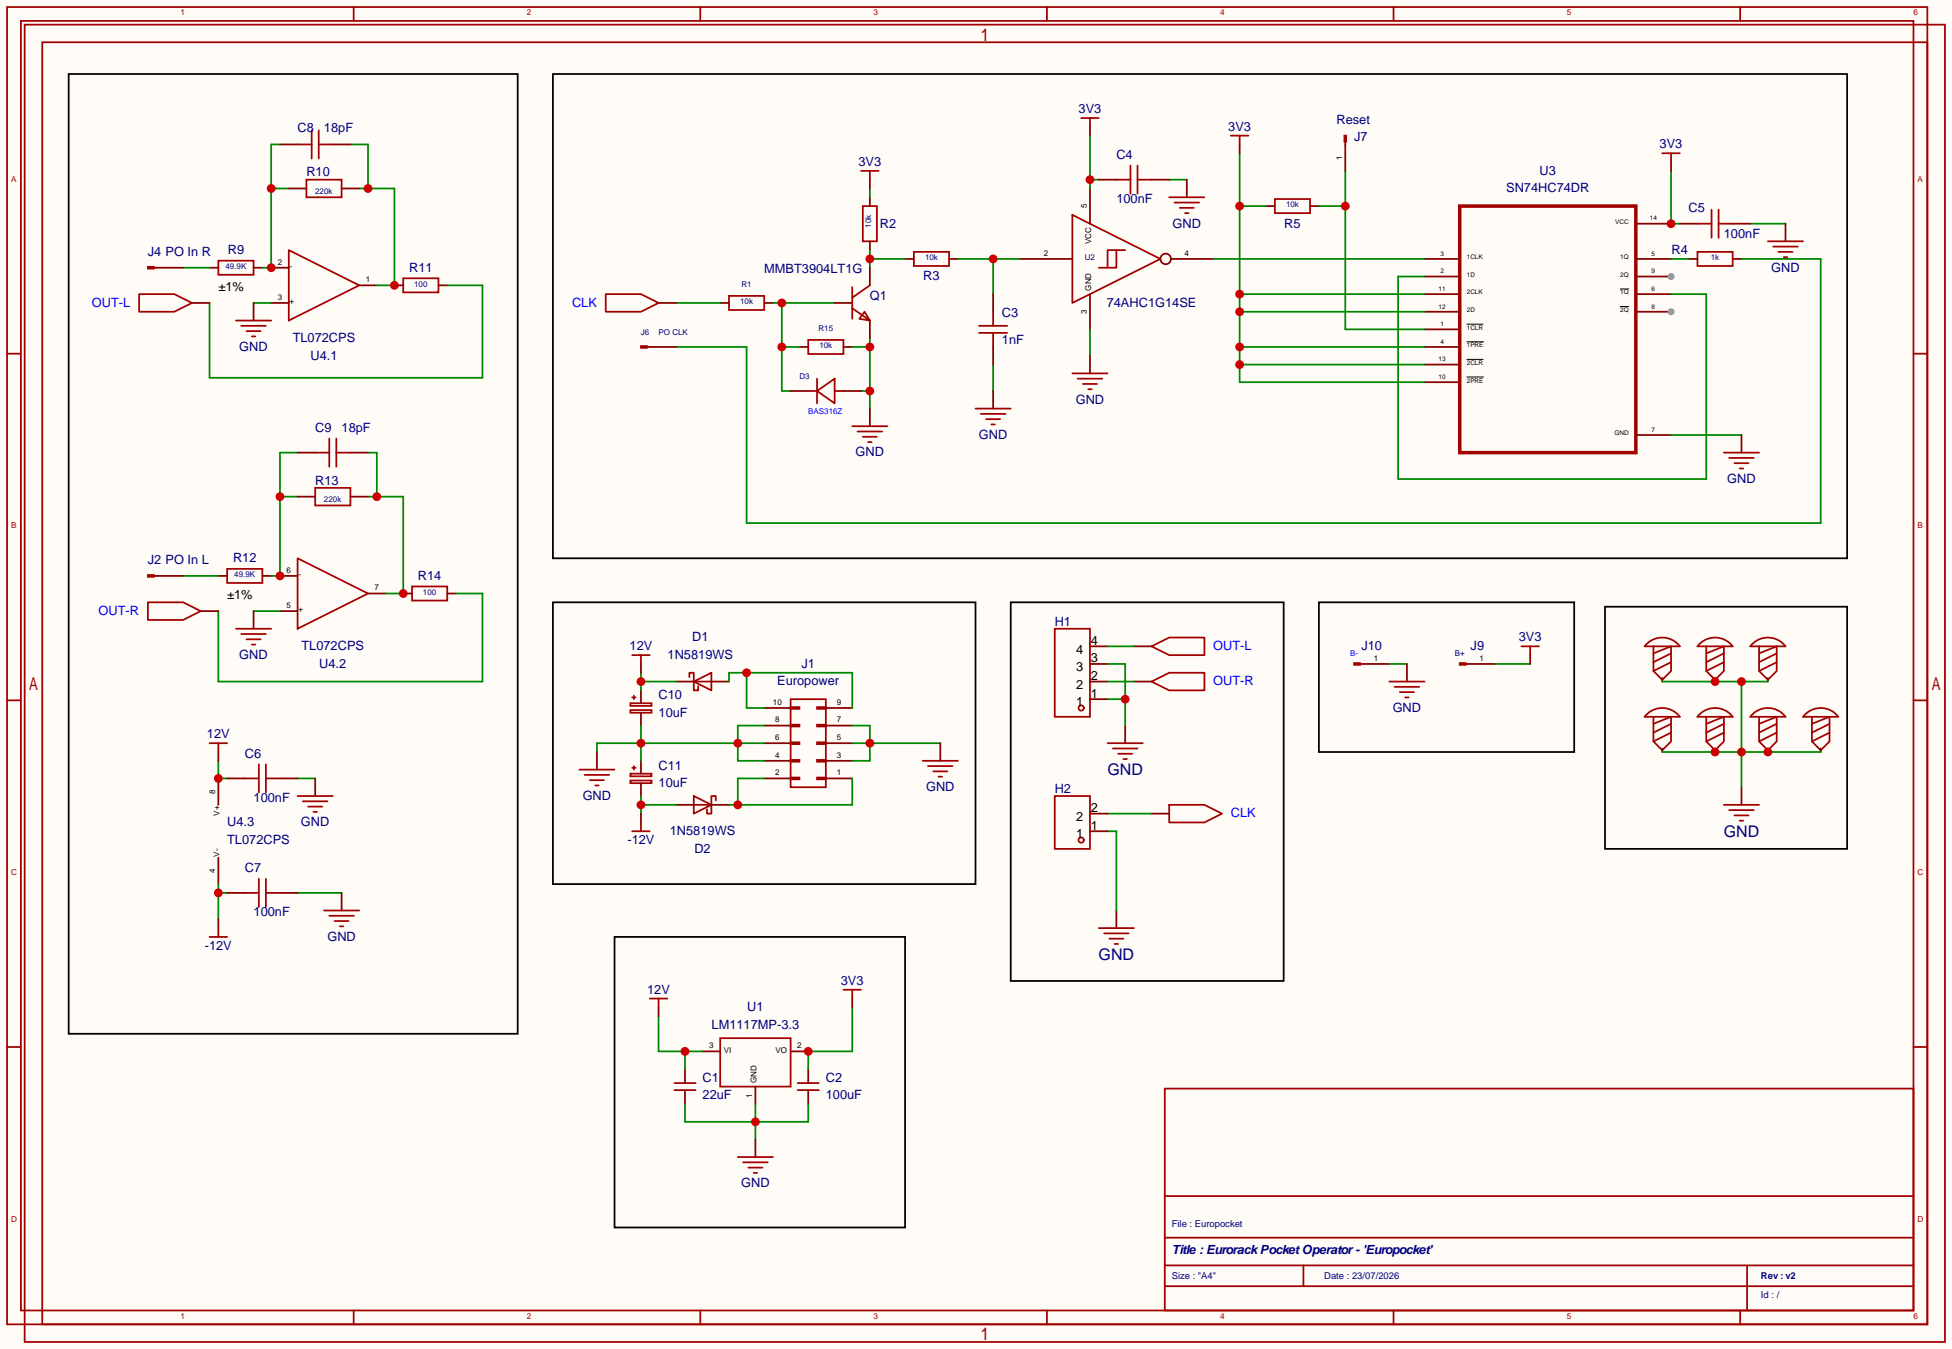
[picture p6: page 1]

File : Europocket
Title : Eurorack Pocket Operator - 'Europocket'

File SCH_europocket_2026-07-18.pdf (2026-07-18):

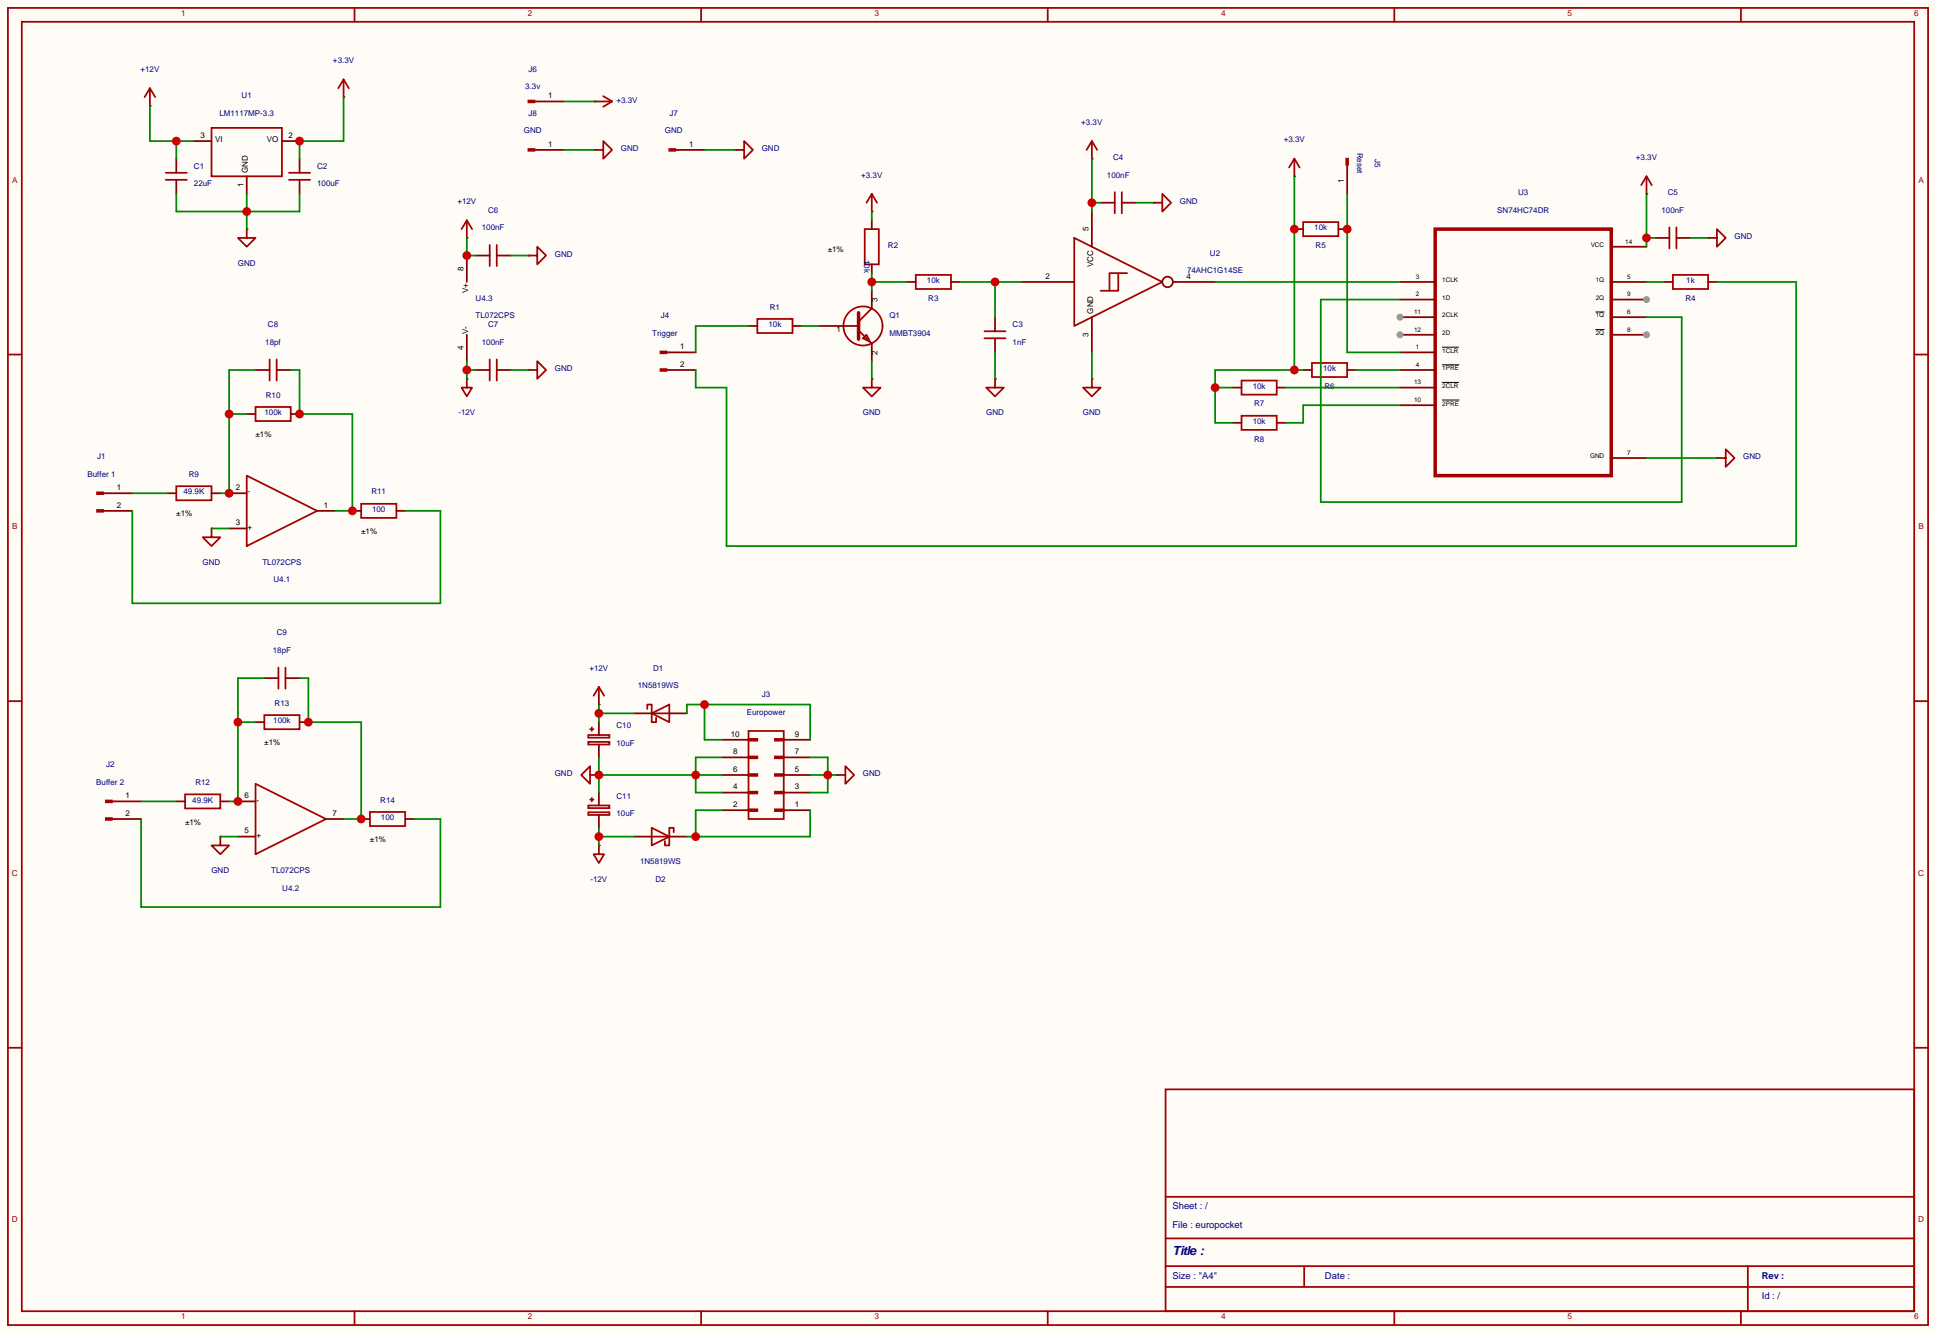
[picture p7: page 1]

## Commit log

2026-07-19 Debug clock divider: wrong Q1 part batch-wide + input threshold fix
    Root-caused the non-working eurorack->PO clock divider to two stacked faults:
    1. PCBWay placed a mismarked part ("1E/A3", dual-diode behavior, zero
    transistor action) instead of MMBT3904 at Q1 on all boards of the
    T-Y6W679717A run. Verified by in-circuit measurements + diode tests;
    replacing with a genuine onsemi MMBT3904 (1AM) restored switching.
    2. Input threshold marginality exposed by the fix: the eurorack clock
    source idles at ~0.68V (not 0V), above a single-Vbe threshold, keeping
    Q1 permanently on. Fixed with a 10k base-emitter pulldown (R15),
    proven on hardware: 5.556Hz in -> 2.747Hz out, clean /2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
2026-07-23 Add gerber outputs, schematic image in README, project file update
    [Drill_PTH_Through.DRL, Drill_PTH_Through_Via.DRL, Gerber_BoardOutlineLayer.GKO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]
2026-08-03 Document v2.1 board: assembly, PO setup, updated hardware design
    Reconcile hardware-design.md against the 2026-08-03 netlist: designator
    remap (power J3->J1, reset J5->J7, audio out on H1, clock in on H2), the
    as-built 220k feedback (x4.41, ~9.7 Vpp from the PO's measured 2.2 Vpp),
    R15/D3 input hardening, and the unused 74HC74 half tied to 3V3 rather
    than left floating. Add a connector/test-point table and a note on
    locating U4 pin 1 from the decoupling caps, since the silkscreen has no
    pin-1 marker.
    README: add Assembly steps -- hot-air removal of the PO's jacks, VHB
    bonding, pad-by-pad wiring, and powering the PO from the module's 3.3 V
    rail in place of its AAA cells. Add Pocket Operator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
2026-08-03 Add bill of materials to README
    Group the BOM by semiconductors, resistors, capacitors, connectors and
    assembly consumables, with quantities for ordering. Values match the
    2026-08-03 netlist.
    hardware-design.md now links to it rather than carrying a second copy,
    so the two documents cannot drift apart.
